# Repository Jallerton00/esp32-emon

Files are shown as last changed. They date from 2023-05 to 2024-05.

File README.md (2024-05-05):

# esp32-emon

A simple energy monitor based off early versions of an energy monitor by openenergymonitor.org.

## Hardware

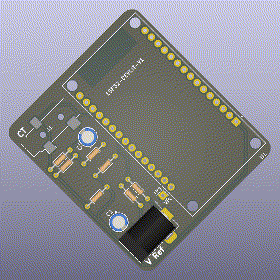
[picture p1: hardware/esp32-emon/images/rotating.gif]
PCB Animation


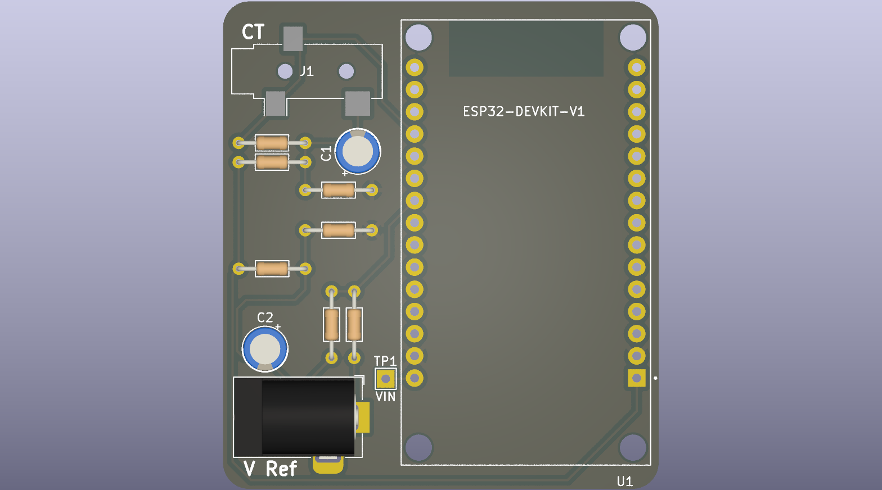
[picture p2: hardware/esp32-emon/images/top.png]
PCB Top

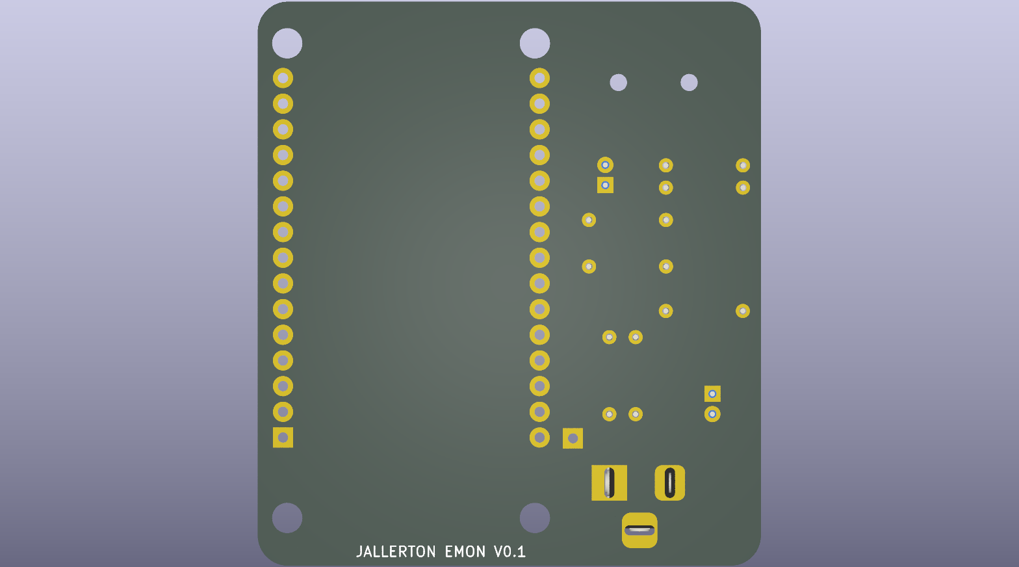
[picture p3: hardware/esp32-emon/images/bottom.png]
PCB Bottom


[PDF Schematic](/hardware/esp32-emon/schematic.pdf)

## Software

The software uses [EmonLib](https://github.com/openenergymonitor/EmonLib) and integrates with HomeAssistant through [ESPHome](https://esphome.io/index.html).

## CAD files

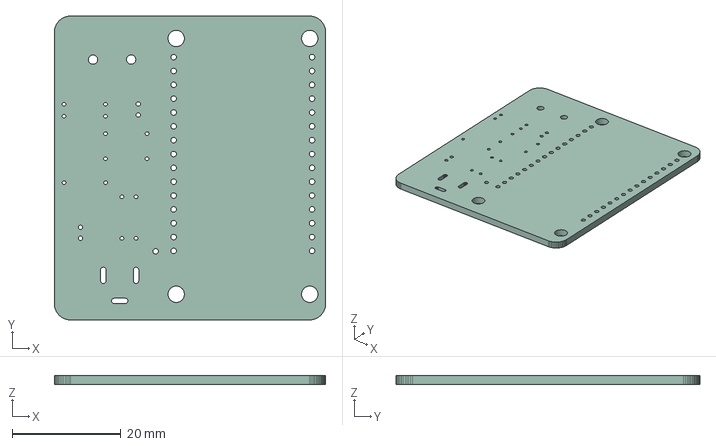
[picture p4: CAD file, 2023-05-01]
3d/esp32-emon.step
49.8 x 55.8 x 1.60 mm

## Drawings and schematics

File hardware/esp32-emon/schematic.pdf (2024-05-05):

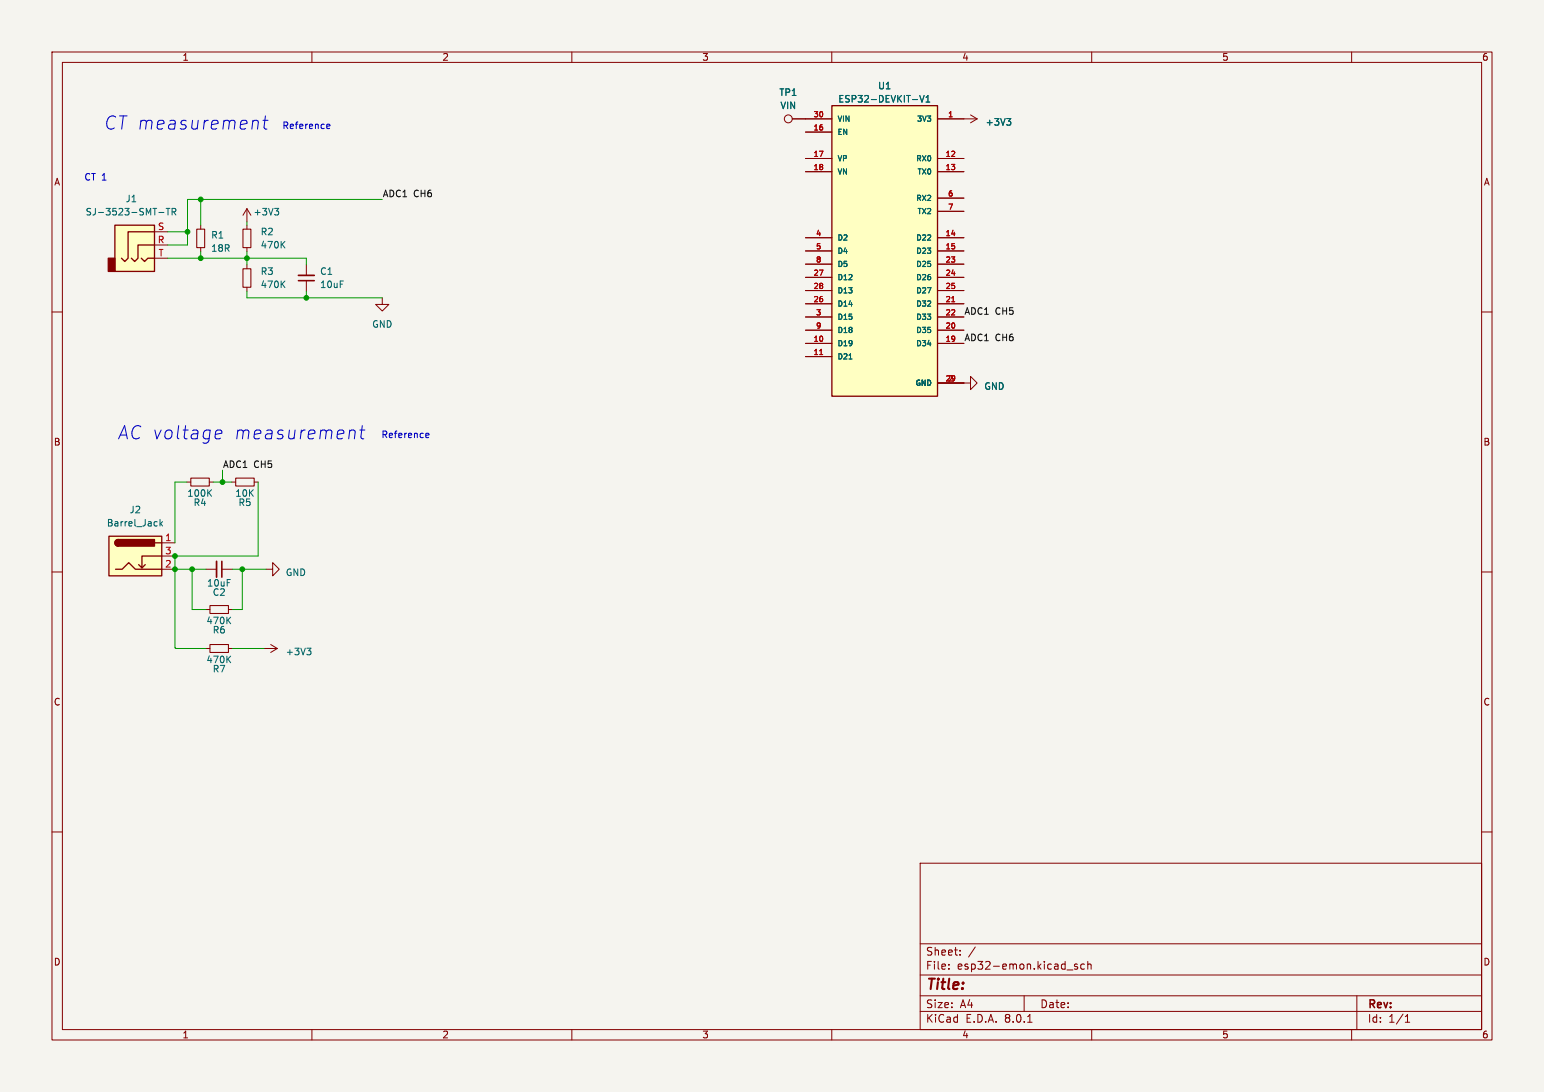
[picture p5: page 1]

Id: 1/1 Title: File: esp32-emon.kicad_sch Sheet: / RST

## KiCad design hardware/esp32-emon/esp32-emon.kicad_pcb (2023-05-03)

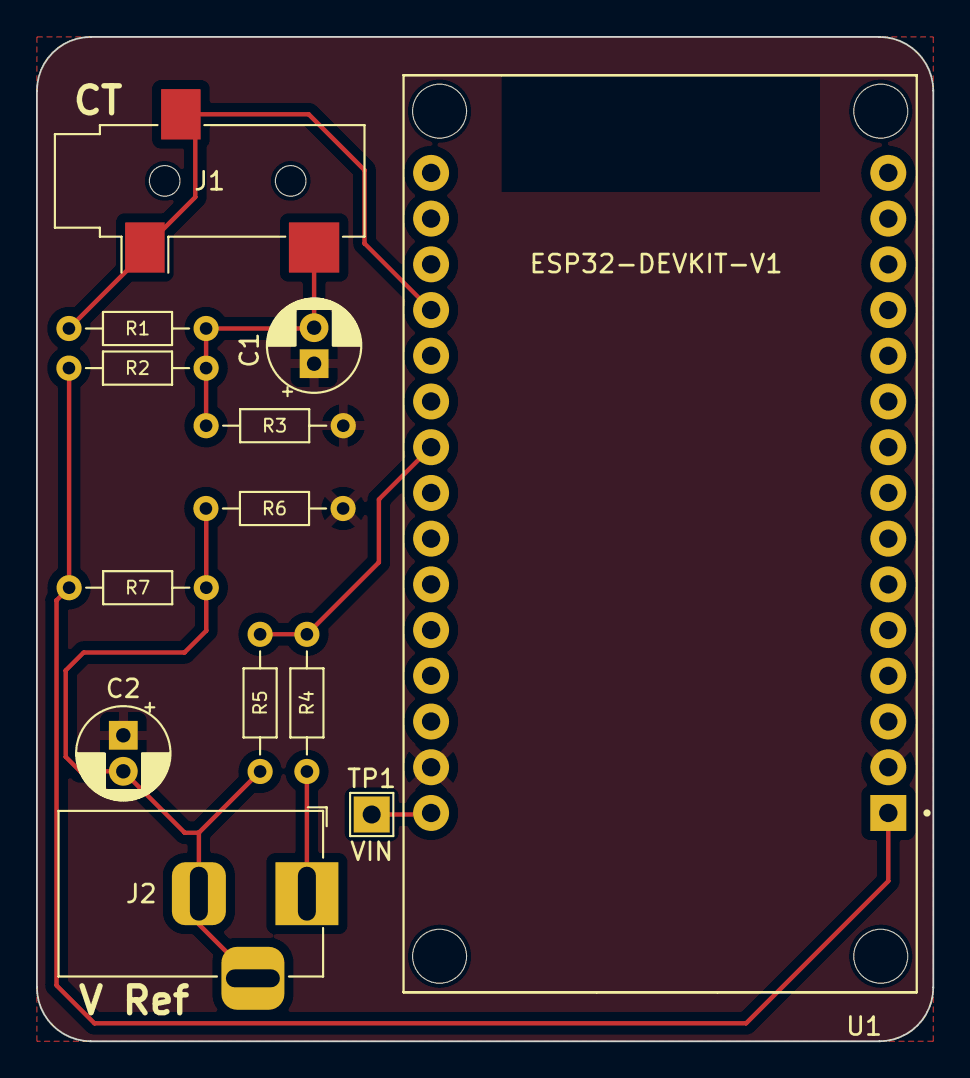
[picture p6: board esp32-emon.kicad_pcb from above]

Board: 2 copper layers, 49.8 x 55.8 mm, 13 parts (0 on the bottom side), 8 nets.

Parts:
C1, C2: 10uF; CP_Radial_D5.0mm_P2.00mm
J1: SJ-3523-SMT-TR; Jack_3.5mm_CUI_SJ-3523-SMT_Horizontal
J2: Barrel_Jack; BarrelJack_Horizontal
R1: 18R; R_Axial_DIN0204_L3.6mm_D1.6mm_P7.62mm_Horizontal
R2, R3, R6, R7: 470K; R_Axial_DIN0204_L3.6mm_D1.6mm_P7.62mm_Horizontal
R4: 100K; R_Axial_DIN0204_L3.6mm_D1.6mm_P7.62mm_Horizontal
R5: 10K; R_Axial_DIN0204_L3.6mm_D1.6mm_P7.62mm_Horizontal
TP1: VIN; TestPoint_THTPad_2.0x2.0mm_Drill1.0mm
U1: ESP32-DEVKIT-V1; MODULE_ESP32_DEVKIT_V1

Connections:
+3V3: R2.1, R7.1, U1.1 (3V3)
/ADC1 CH5: R4.1, R5.2, U1.22 (D33)
/ADC1 CH6: J1.R, J1.S, R1.2, U1.19 (D34)
GND: C1.1, C2.1, R3.2, R6.1, U1.2 (GND), U1.29 (GND)
unnamed: C1.2, J1.T, R1.1, R2.2, R3.1
unnamed: C2.2, J2.2, J2.3, R5.1, R6.2, R7.2
unnamed: J2.1, R4.2
unnamed: TP1.1, U1.30 (VIN)

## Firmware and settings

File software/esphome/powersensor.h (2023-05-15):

#include "esphome.h"
#include "EmonLib.h"

#define VOLTAGE_PIN 33
#define VOLTAGE_CALIBRATION 57.19
#define PHASE_CALIBRATION 1.28
#define CURRENT_1_CALIBRATION 26.4
#define CURRENT_1_PIN 34

class MyPowerSensor : public PollingComponent, public Sensor {
 public:
  EnergyMonitor emon1;
  Sensor *realpower_sensor = new Sensor();
  Sensor *apparentpower_sensor = new Sensor();
  Sensor *powerfactor_sensor = new Sensor();
  Sensor *voltage_sensor = new Sensor();
  Sensor *current_sensor = new Sensor();
  MyPowerSensor() : PollingComponent(2000) { }
  
  void setup() override {
   voltage_sensor->set_unit_of_measurement("V");
   voltage_sensor->set_accuracy_decimals(2);
   voltage_sensor->set_device_class("voltage");

   current_sensor->set_unit_of_measurement("A");
   current_sensor->set_accuracy_decimals(2);
   current_sensor->set_device_class("current");

   realpower_sensor->set_unit_of_measurement("W");
   realpower_sensor->set_accuracy_decimals(2);
   realpower_sensor->set_device_class("power");

   apparentpower_sensor->set_unit_of_measurement("VA");
   apparentpower_sensor->set_accuracy_decimals(2);
   apparentpower_sensor->set_device_class("power");

   powerfactor_sensor->set_accuracy_decimals(2);
   powerfactor_sensor->set_device_class("power");


   emon1.voltage(VOLTAGE_PIN, VOLTAGE_CALIBRATION, PHASE_CALIBRATION);
   emon1.current(CURRENT_1_PIN, CURRENT_1_CALIBRATION);
  }
  
  void update() override {
   emon1.calcVI(20,2000);
   float realPower = emon1.realPower;
   realpower_sensor->publish_state(realPower);
   float apparentPower = emon1.apparentPower;
   apparentpower_sensor->publish_state(apparentPower);
   float powerFactor= emon1.powerFactor;
   powerfactor_sensor->publish_state(powerFactor);
   voltage_sensor->publish_state(emon1.Vrms);
   current_sensor->publish_state(emon1.Irms);
   }
};

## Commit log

2023-05-01 Updates for v0.1
    [esp32-emon.kicad_pcb, esp32-emon.kicad_sch]
2023-05-01 v0.1 order
    [esp32-emon-B_Cu.gbr, esp32-emon-B_Mask.gbr, esp32-emon-B_Paste.gbr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]
2023-05-01 Add 3d models
    [esp32-emon.step]
2023-05-03 Initial working voltage
2023-05-03 Update from 1K to 10K
    [esp32-emon.kicad_pcb, esp32-emon.kicad_sch]
2023-05-03 Update calibration for new resistors
2023-05-15 Calibrate (roughly) after PCB installation
2023-05-15 Add device classes and manage sensor units from custom integration (rather than YAML)
2024-05-05 Update images, schematic and gerbers
2024-05-05 Update main.yaml and remove old manufacture files
    [esp32-emon-B_Cu.gbr, esp32-emon-B_Mask.gbr, esp32-emon-B_Paste.gbr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]
2026-11-08 Add case models and DXF
    Claude-Session: https://claude.ai/code/session_01DAzFVPMY5vhwhKCwin7uuh
2026-11-08 Remove accidental stash conflict markers from powersensor.h
    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
